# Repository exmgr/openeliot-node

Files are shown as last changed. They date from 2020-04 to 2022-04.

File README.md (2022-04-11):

## Εισαγωγή
Το OpenELIoT Νode αποτελεί τον κόμβο καταγραφής δεδομένων από περιβαλλοντικούς αισθητήρες και είναι μέρος του έργου [Open ELIoT](https://github.com/exmgr/OpenELIoT). Αποτελείται από την ίδια την ηλεκτρονική συσκευή καταγραφής και το υλισμικό της το οποίο βρίσκεται σε αυτό το αποθετήριο. 
Είναι ένα αυτόνομα σύστημα καταγραφής κατασκευασμένο να λειτουργεί για μεγάλα χρονικά διαστήματα σε απομακρυσμένες περιοχές αντλώντας ηλιακή ενέργεια για την φόρτιση των μπαταριών του και το περίβλημά του είναι ανθεκτικό στις καιρικές συνθήκες (ήλιος, βροχή, υγρασία).

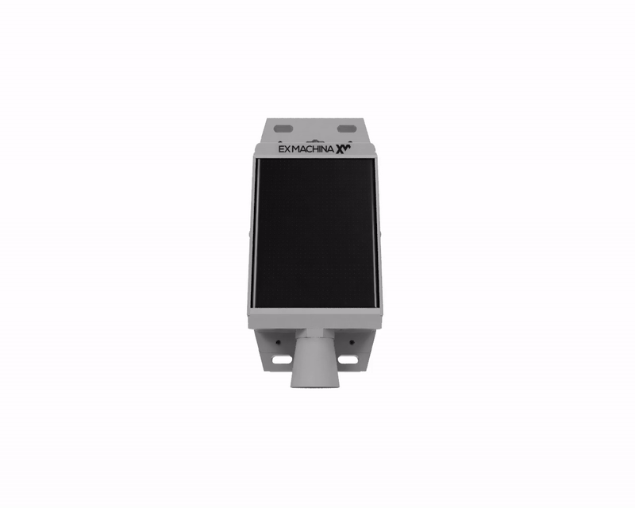
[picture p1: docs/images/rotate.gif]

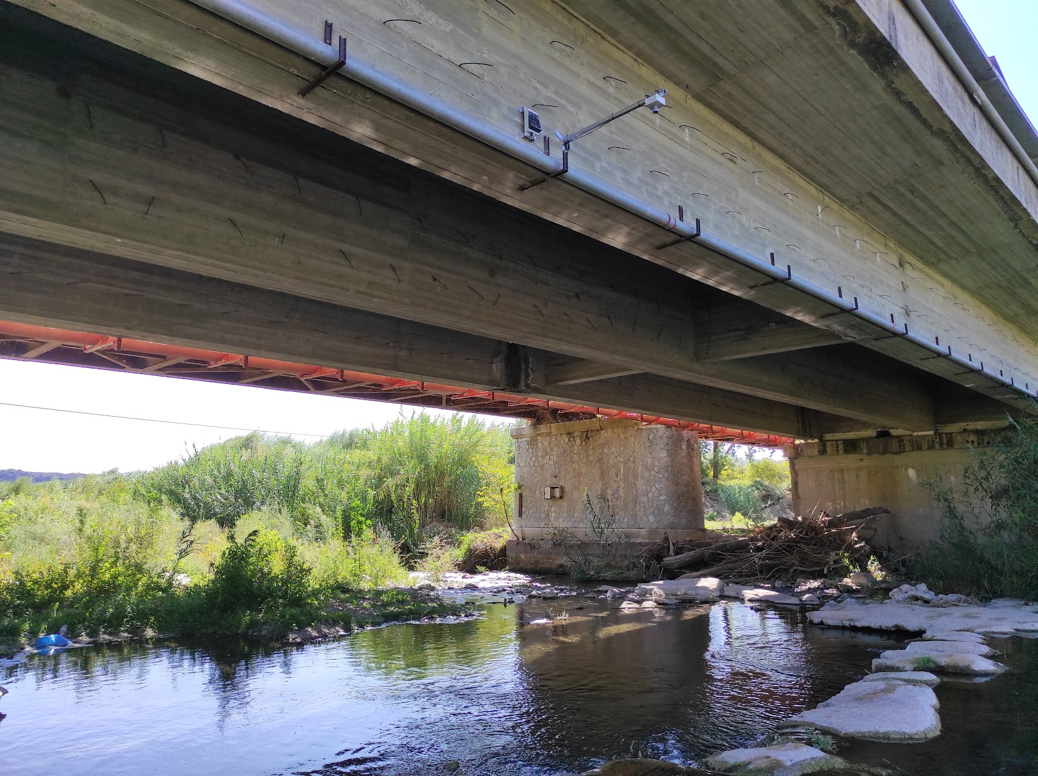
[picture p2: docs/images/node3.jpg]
OpenELIoT Node


## Αρχιτεκτονική Node

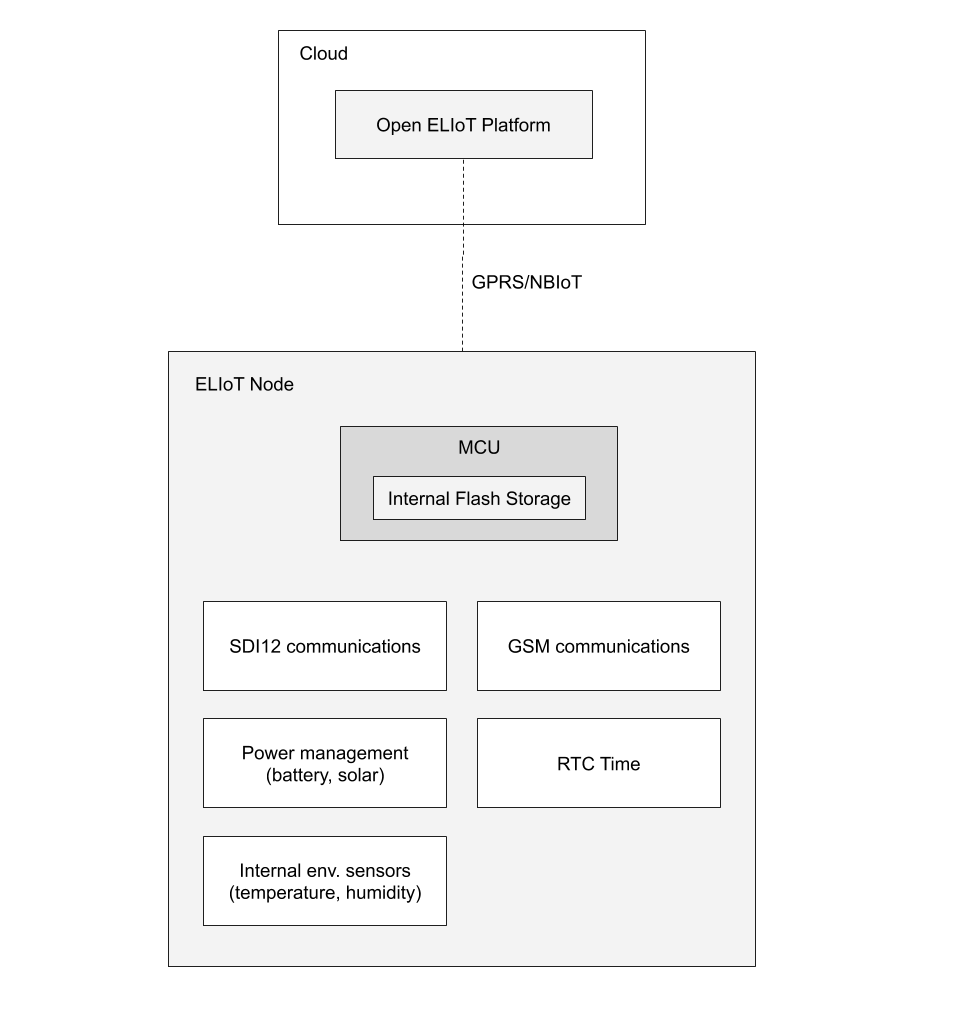
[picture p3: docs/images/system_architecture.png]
Αρχιτεκτονική συστήματος


Το ELIoT node αποτελεί κεντρικό δομικό στοιχείο του κάθε σταθμού καταγραφής OpenELIoT, στον οποίο συνδέονται όλοι οι αισθητήρες των οποίον τα δεδομένα καταγράφει, αποθηκεύει και αποστέλλει στην πλατφόρμα. Αποτελείται από κυκλώματα που του επιτρέπουν να επικοινωνεί μέσω ποικίλων πρωτοκόλλων με τους αισθητήρες, κυκλώματα διαχείρισης ενέργειας για αυτόνομη λειτουργία με φόρτιση των μπαταριών από τον ήλιο και υποστήριξη τεχνολογιών ασύρματης επικοινωνίας για αποστολή των δεδομένων.

## Τεχνικός οδηγός
Αναλυτική περιγραφή του συστήματος, οδηγίες για την κατασκευή, ρύθμιση και τον προγραμματισμού του υλισμικού ενός OpenELIoT Node βρίσκονται στον [τεχνικό οδηγό](docs/technical_guide.pdf)

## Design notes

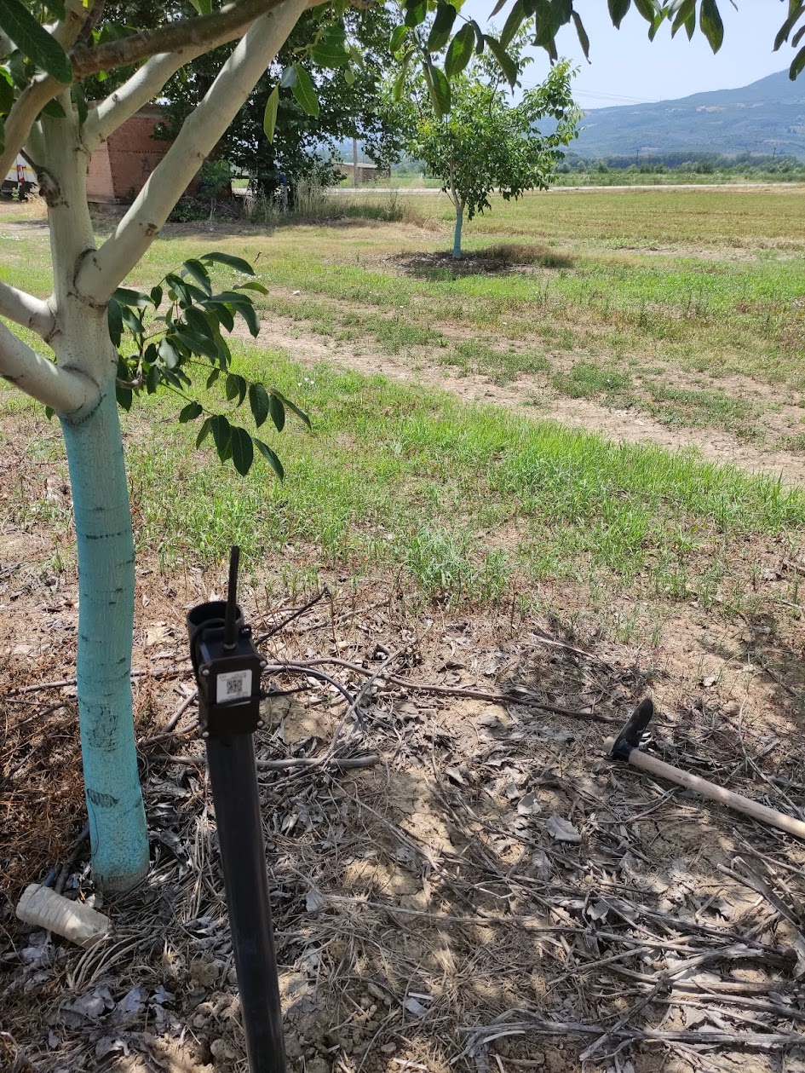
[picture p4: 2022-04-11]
docs/images/soil.jpg

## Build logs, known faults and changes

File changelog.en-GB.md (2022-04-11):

[1.64]
* Time source priority changed to HTTP first.

[1.63]
* CHanged battery sleep thersholds to 25/35%.

[1.61]
* Improved filtering of ADC battery measurement
* Light sensor tuning
* Detect system time drift using external RTC
* Check RTC drift on wakeup-self-test
* Added check to prevent significant time changes on RTC sync to prevent time errors

[1.58]
* Improved RTC auto sync
* Log RTC time source on sync for debugging

[1.56]
* Improved data acquisition from MaxBotix level sensor

[1.55]
* Decreased RTC auto sync interval to half a day

[1.54]
* Added UV index to weather telemetry

[1.53]
* Moved DFRobot water level sensor to another serial port due to stability issues 

[1.52]
* Light sensor stability bug fixes
* Log raw value of water presence sensor
* DFRobot ultrasonic serial port bug fix

[1.51]
* More flags submitted as attributes to aid with debugging

[1.50]
* Added IPFS support. Weather station measurements are submitted to IPFS during data submission.

[1.49]
* RTC auto-sync feature, where RTC is automatically synced on preset intervals.

[1.48]
* Added NTP sync support to TSIM7000.

[1.45]
* Lightning sensor tuned for improved precision. 

[1.44]
* Device can now keep working if external RTC fails by relying solely on the internal RTC.

[1.43]
* More robust handling on errors during data submission.
* Improved wind speed calculations for FineOffset weather stations.
* Added lightning sensor mode selection switch
* Added support for LTC2941 coulomb counter.
* Added INA218 current monitor support for monitoring solar power.

[1.42]
* Added Lightning sensor on/off flag.
* Added RTC sync remote control command.

[1.41]
* Added Aquatroll600 support.

[1.36]
* Added support for AS3936 lightning sensor.

[1.35]
* Added support DFRobot A02YYUW ultrasonic sensor. 

[1.33]
* FineOffset RF sniffing is automatically disabled to conserve energy after a number of unsuccessful attempts to receive a packet from a weather station.

[1.32]
* Added FineOffset sniffer auto-scan feature where the device listens for packets from a weather station and pairs itself to that specific weather station.
* Device now sleeps when waiting for the RF module to return a packet and is awaken on interrupt when a packet is received, to conserve energy.
* Submit more detailed configuration as device attributes.

[1.24]
* Improved ultrasonic sensor data filtering.

[1.23]
* Soil moisture measurement intervals can now be changed via remote control.

[1.19]
* Device can now be booted into "config mode" by holding user button for 3 seconds during boot. In config mode, device-specific configuration can be set via a serial console.

[1.18]
* Added support for RF sniffing telemetry data from FineOffset weather stations and logging them as telemetry.

[1.17]
* Implemented custom SDI12 driver.
* Added support for DFRobot throw-in liquid pressure sensor.
* Added support for Teros12 soil moisture sensor.
* Added support for DFRobot ultrasonic level sensor.
* Added support for serial channel on Maxbotix ultrasonic sensors.
* Added support for Aquatroll500 water quality sensor.

[1.16]
* Added TTGo TSIM support

[1.14]
* Adafruit FONA support discontinued
* SDI12 communications can be logged and submitted to TB for debugging.

[1.13]
* Added support for redirecting serial debug output via WiFi to timber.io for debugging.

[1.12]
* Added debug message level macros
* Added Thingsboard fallback device for when user config is corrupted.

[1.11]
* Sleep/sensor intervals are now measured as a reference of current time instead of the device boot time for more predictable operation.
* Added dew point to weather data

[1.8]
* Use external RTC to compensate drifting of external RTC for more precise wakeup intervals.

[1.7]
* Added support for Atmos41 weather station.
* SPIFFS file system can be formmated via remote-control.
* Added enable/disable flags for water level/quality sensors.
* Application-config flags are submitted as Thingsboard device attributes.

[1.3]
* Added support for PWM channel on MaxBotix ultrasonic sensors.
* Current device configuration is submitted as Thingsboard device attributes.

[1.2]
* Added low battery mode in which user-set sleep intervals are ignored and preset low-rate intervals are used instead to save battery.
* Added sleep-charge mode which puts the device in sleep when battery level is critically low and all functionality is disabled. Device functionality is restored only when battery is charged above a preset level.

[1.1]
* More detailed logging.
* Self-test after OTA. If fails, firmware is rolled back to previous version.

[1.0]
* Added support for OTA.
* GSM backend completely refactored to use TinyGSM.
* Added per-board config file.
* Added Support for WiPy.
* Added support for Adafruit Feather.

[0.3]
* Read battery voltage/pct from GSM module and add as diagnostics.
* Sync time from HTTP when everything else fails.
* Added BME280 for monitoring internal environment conditions.

[0.2]
* Send diagnostics as telemetry to Thingsboard.
* Added NBIoT support when using SIM7000.
* Added NodeMCU support.

[0.1]
* Added TTGO TFox compatibility.
* Added remote config.

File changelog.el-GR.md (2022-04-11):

[1.64]
* Time source priority changed to HTTP first.

[1.63]
* CHanged battery sleep thersholds to 25/35%.

[1.61]
* Βελτίωση φιλτραρίσματος της καταγραφής τάσης της μπαταρίας από ADC
* Συντονισμός του αισθητήρα κεραυνών
* Αναγνώριση και διόρθωση της απόκλισης της ώρας συστήματος χρησιμοποιώντας το εξωτερικό RTC
* ΈΛεγχος της απόκλισης της ώρας κατα το ξύπνημα στο self-test.
* Προστέθηκε έλεγχος που εμποδίζει τις μεγάλες μεταβολές ώρας κατα τον συγχρονισμό για αποφυγή μη έγκυρης ώρας

[1.58]
* Βελτίωση συγχρονσιμού ώρας
* Καταγραφή της πηγής της ώρας για αποσφαλμάτωση

[1.56]
* Βελτίωση ανάγνωσης δεδομένων από τον αισθητήρα στάθμης MaxBotix

[1.55]
* Μείωση του χρόνου αυτόματου συγχρονισμού ώρας σε μισή μέρα

[1.54]
* Προσθήκη δείκτη UV στην τηλεμετρία καιρού

[1.53]
* Μετακίνηση του αισθητήρα στάθμης DFRobot σε εναλλακτική σειριακή θύρα λόγω προβλημάτων σταθερότητας

[1.52]
* Βελτιστοποιημένη σταθερότητα αισθητήρα κεραυνών
* Διόρθωση σφάλματος στη σειριακή θύρα του ηχοβολιστικού DFRobot

[1.51]
* Εκτεταμένη αποστολή καταγραφής για διευκόλυνση της αποσφαλμάτωσης

[1.50]
* Προσθήκη υποστήριξης IPFS.
* Αποστολή δεδομένων μετεωρολογικού σταθμού στο IPFS

[1.49]
* Λειτουργία αυτόματου συγχρονισμού ρολογιού ανά τακτά χρονικά διαστήματα.

[1.48]
* Προσθήκη συγχρονισμού ώρας μέσω NTP στο TSIM7000.

[1.45]
* Βελτίωση των ρυθμίσεων του αισθητήρα κεραυνών για βελτιωμένη ακρίβεια.

[1.44]
* Η συσκευή μπορεί πλέον να λειτουργεί ακόμα και μετά από αποτυχία του εξωτερικού RTC, λειτουργόντας μόνο με τη χρήση του εσωτερικού RTC του ESP32.

[1.43]
* Ανθεκτικότερος χειρισμός σφαλμάτων κατά την αποστολή δεδομένων.
* Βελτίωση των υπολογισμών της ταχύτητας του ανέμου στους μετεωρολογικούς σταθμόυς FineOffset.
* Προστέθηκε διακόπτης επιλογής λειτουργίας του αισθητήρα κεραυνών.
* Προστέθηκε υποστήριξη του LTC2941 coulomb counter.
* Προστέθηκε υποστήριξη ΙΝΑ218 current monitor για παρακολούθηση ενέργειας του ηλιακού πάνελ.

[1.42]
* Προσθήκη διακόπτη ενεργ./απενεργ. για τον αισθτήρα κεραυνών.
* Προστέθηκε εντολή απομακρυσμένου ελέγχου για συγχρονισμό του RTC.

[1.41]
* Προσθήκη υποστήριξης του αισθητήρα ποιότητας νερού Aquatroll600.

[1.36]
* Προσθήκη υποστήριξης του αισθητήρα κεραυνών AS3936.

[1.35]
* Προσθήκη υποστήριξης για τον αισθητήρα στάθμης υπερήχων DFRobot A02YYUW.

[1.33]
* To RF sniffing απενεργοποιείται αυτόματα μετά απο αριθμό διαδοχικών αποτυχιών λήψης πακέτου από μετεωρολογικό σταθμό, για εξοικονόμηση ενέργειας.

[1.32]
* Προστέθηκε λειτουργία αυτόματης αναζήτησης στον FineOffset sniffer, κατα την οποία η συσκευή "ακούει" για πακέτα δεδομένων από μετεωρολογικούς σταθμους FineOffset και έπειτα δημιουργεί σύζευξη με τον συγκεκριμένο σταθμό.
* Η συσκευή βρίσκεται σε λειτουργία ύπνου όσο αναμένει πακέτα από το RF module, και ξυπνάει μόνο όταν ληφθεί το πακέτο γι εξοικονόμηση ενέργειας.
* Αποστολή περισσότερων ρυθμίσεων ως Thingsboard device attributes.

[1.24]
* Βελτίωση φιλτραρίσματος αναγνωσμένων δεδομένων των αισθητήρων υπερήχων.

[1.23]
* Ο χρόνος δειγματοληψίας του αισθητήρα υγρασίας εδάφους μπορεί να ρυθμιστεί απομακρυσμένα.

[1.19]
* Προσθήκη υποστήριξης λειτουργίας εύκολης ρύθμισης "config mode". Η συσκευή μπορεί να ξεκινήσει σε αυτη τη λειτουργία πατώντας το κουμπί χρήστη για 3 δευτ. κατά την εκκίνηση. Έπειτα με τη βοήθεια μιας σειριακής κονσόλας η συσκευή μπορεί να ρυθμιστεί με απλές εντολές.

[1.18]
* Προσθήκη υποστήριξης RF sniffing των μετεωρολογικών σταθμών της FineOffset και καταγραφή των δεδομένων τηλεμετρίας.

[1.17]
* Υλοποιήθηκε custom SDI12 driver.
* Προσθήκη υποστήριξης για τον αισθητήρα DFRobot throw-in liquid pressure sensor.
* Προσθήκη υποστήριξης για τον αισθητήρα υγρασίας εδάφους Teros12.
* Προσθήκη υποστήριξης για τον ultrasonic αισθητήρα στάθμης της DFRobot.
* Προσθήκη υποστήριξης σειριακού καναλιού για τον αισθητήρα στάθμης υπερήχων Maxbotix. 
* Προσθήκη υποστήριξης για τον αισθητήρα ποιότητας νερού Aquatroll500.

[1.16]
* Προσθήκη υποστήριξης για την πλακέτα TTGo TSIM.

[1.14]
* Αφαιρέθηκε η βιβλιοθήκη Adafruit FONA.
* Οι επικοινωνίες μεταξύ των συσκευών SDI12 μπορούν πλέον να καταγραφούν και να αποσταλούν ως τηλεμετρία στο Thingsboard για αποσφαλμάτωση.

[1.13]
* Η έξοδος της κονσόλας αποσφαλμάτωσης μπορεί να ανακατευθυνθεί μέσω WiFi στην υπηρεσία Timber.io, για διευκόλυνση της αποσφαλμάτωσης.

[1.12]
* Προστέθηκαν επίπεδα στα μηνύματα αποσφαλμάτωσης της κονσόλας (debug level macros)
* Προστέθηκε fallback συσκευή Thingsbaord, για την περίπτωση που καταστραφούν οι ρυθμίσεις του χρήστη στην εσωτερική μνήμη.

[1.11]
* Οι χρόνοι δειγματοληψίας πλέον υπολογίζονται με σημείο αναφοράς την τρέχουσα ώρα αντί για τον χρόνο τον οποίο μπήκε σε λειτουργία η συσκευή, ώστε η ώρα δειγματοληψίας να είναι προβλέψιμη.
* Προστέθηκε η παράμετρος "σημείο δρόσου" στις παραμέτρους του μετεωρολογικού σταθμου.
[1.8]
* Χρήση του εξωτερικού RTC για διόρθωση του drift του εσωτερικού RTC, για μεγαλύτερη ακρίβεια στους χρόνους δειγματοληψίας.

[1.7]
* Προσθήκη υποστήριξης του μετεωρολογικού σταθμου Atmos41.
* Το σύστημα αρχείων SPIFFS μπορεί να διαμορφωθεί μέσω απομακρυσμένου ελέγχου.
* Προστέθηκε διακόπτης ενεργ./απενεργοποίησης των αισθητήρων στάθμης/ποιότητας νερού.
* Οι ρυθμίσεις του app_config αποστέλλονται ως Thingsboard device attributes κατά την αποστολή δεδομένων για διευκόλυνση της αποσφαλμάτωσης.

[1.3]
* Προσθήκη υποστήριξης του PWM καναλιού στους MaxBotix ultrasonic αισθητήρες.
* Οι τρέχουσες ρυθμίσεις της συσκευής αποστέλλονται ως Thingsboard device attributes.

[1.2]
* Προστέθηκε λειτουργία χαμηλής μπαταρίας κατά την οποία η ρυθμίσεις χρόνων δειγματοληψίας του χρήστη αγνοούνται και η συσκευή μπαίνει σε λειτουργία αργής δειγματοληψίας για εξοικονόμηση ενέργειας.
* Προστέθηκε λειτουργία sleep-charge κατά την οποία η συσκευή μπαίνει σε λειτουργία ύπνου για εξοικονόμηση ενέργειας όταν η μπαταρία βρίσκεται σε κρίσιμα χαμηλά επίπεδα. Η πλήρης λειτουργικότητα της συσκευής επανέρχεται μόνο όταν το επίπεδο φόρτισης της μπαταρίας ανέβει πάνω από ένα προκαθορισμένο όριο.

[1.1]
* Αναλυτικότερη καταγραφή συμβάντων και σφαλμάτων.
* Αυτοέλεγχος της συσκευής μετά το ΟΤΑ. Σε περίπτωση αποτυχίας, το υλισμικό επανέρχεται στην προηγούμενη έκδοση.

[1.0]
* Προσθήκη ΟΤΑ (αποστολή απομακρυσμένων αναβαθμίσεων υλισμικού).
* Λειτουργικότητα GSM γράφτηκε από την αρχή για χρήση της βιβλιοθήκης TinyGSM.
* Προσθήκη αρχείου ρυθμίσεων ανα πλακέτα ανάπτυξης,
* Προσθήκη υποστήριξης πλακέτας WiPy.
* Προσθήκη υποστήριξης πλακέτας Adafruit Feather

[0.3]
* Ανάγνωση τάσης/κατάστασης φόρτισης μπαταρίας από το GSM module και αποθήκευση στα διαγνωστικά.
* Συγχρονισμός ώρας μέσω ΗΤΤP όταν οι υπόλοιπο μέθοδοι συγχρονισμού αποτύχουν.
* Προσθήκη του αισθητήρα ΒΜΕ280 για παρακολούθηση των εσωτερικών συνθηκών της συσκευής.

[0.2]
* Αποστολή διαγνωστικών ως τηλεμετρία στο Thingsboard.
* Προσθτέθηκε υποστήριξη NBIoT όταν υπάρχει διαθέσιμο το SIM7000.
* Προσθήκη υποστήριξης της πλακέτας NodeMCU.

[0.1]
* Προστέθηκε υποστήριξη της πλακέτας TTGO TFox.
* Προσθήκη δυνατότητας απομακρυσμένου ελέγχου.

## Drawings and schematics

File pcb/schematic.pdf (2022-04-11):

### BME280 Module (i2c mode)

### Generic AHT10 module

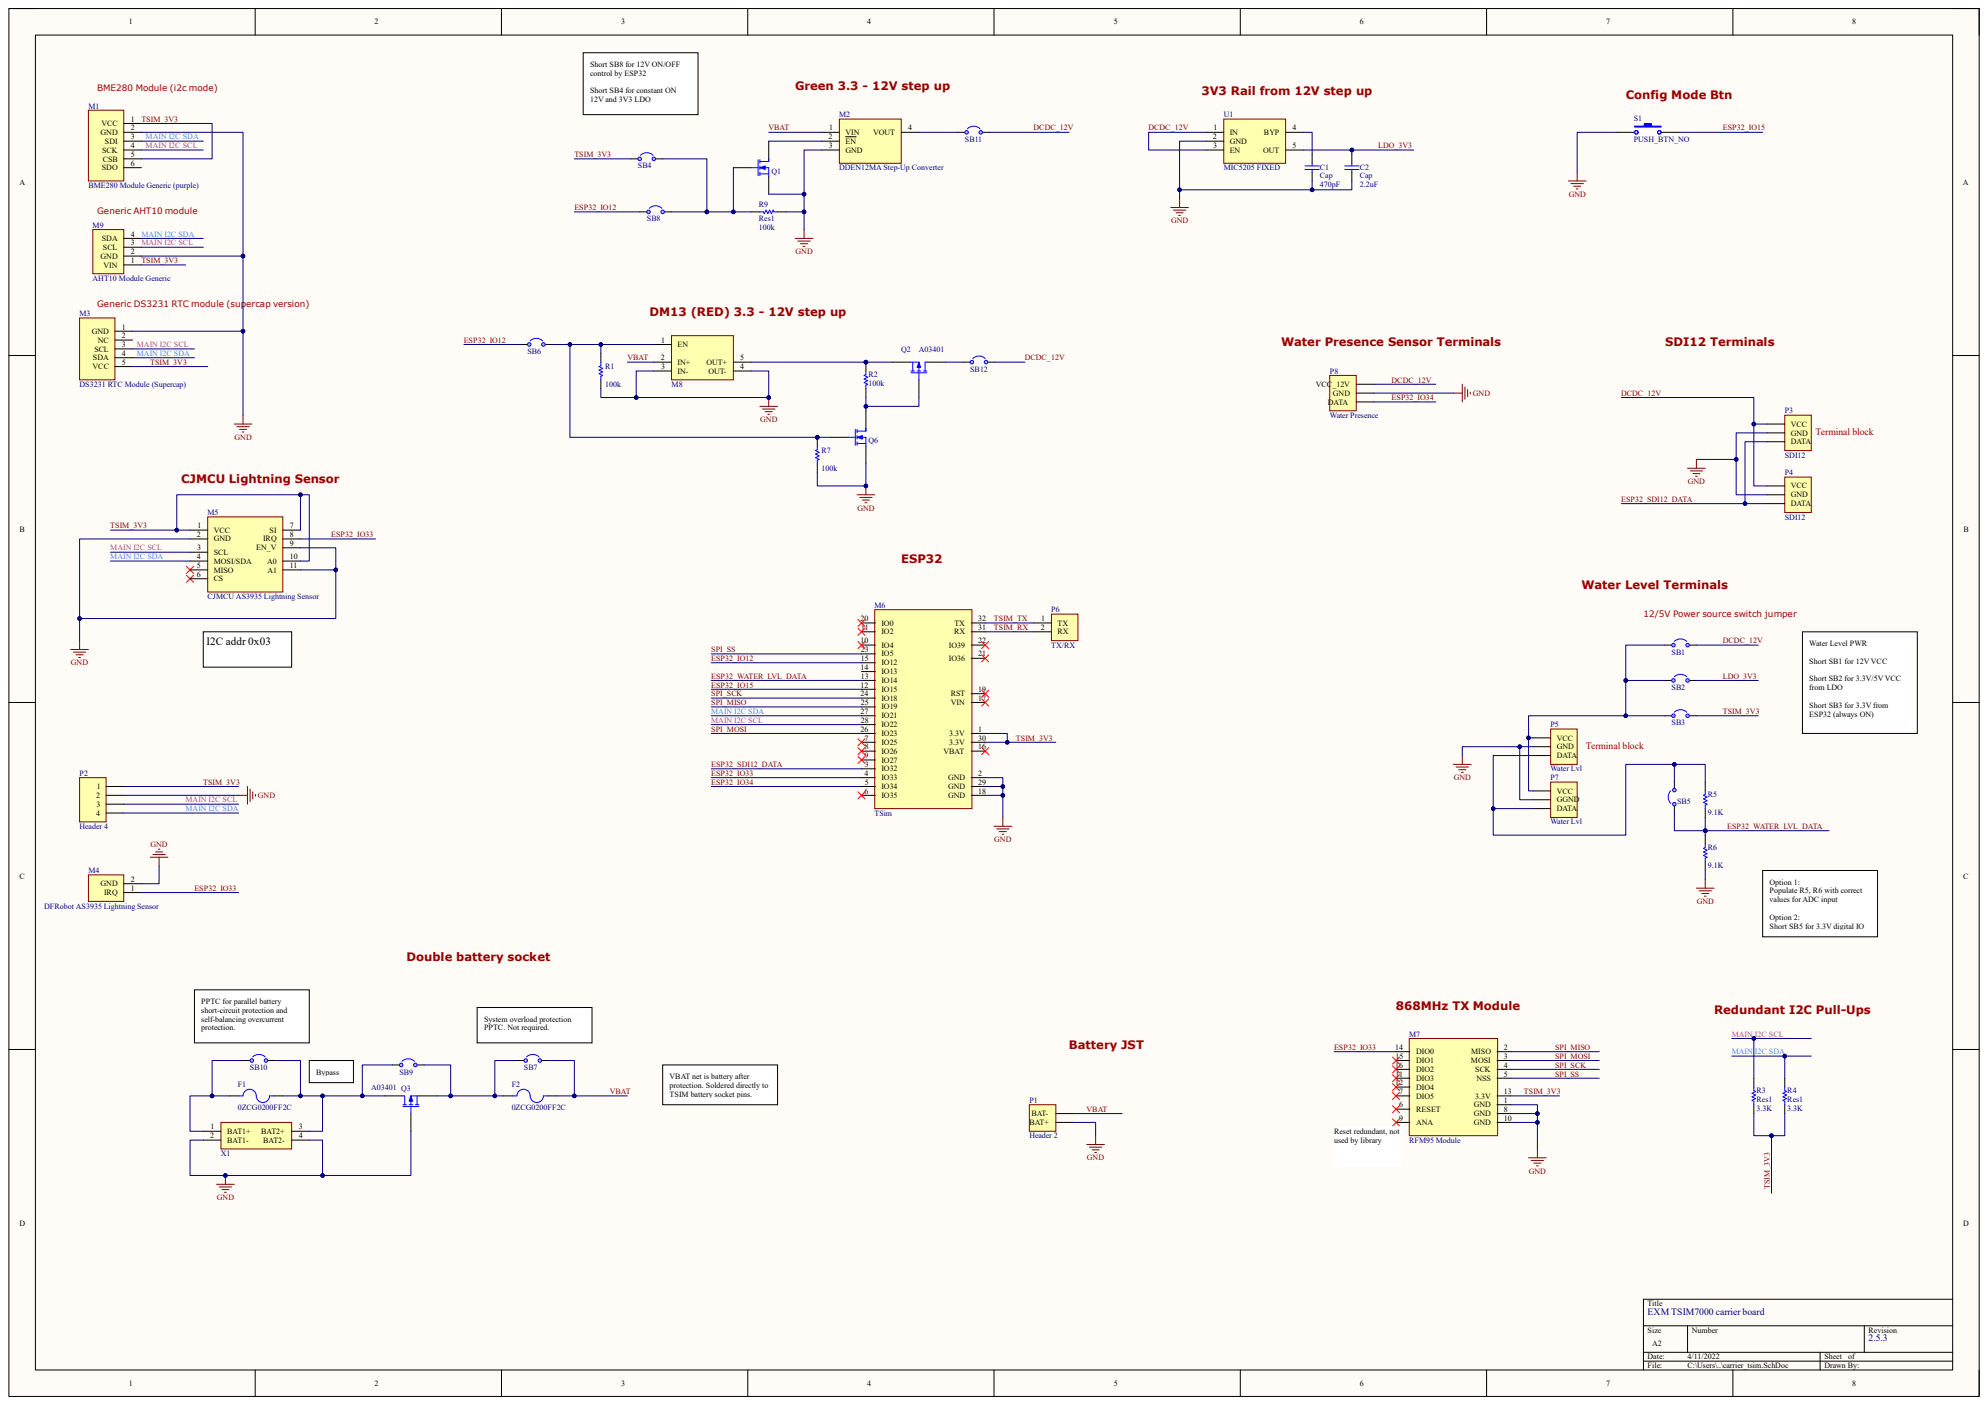
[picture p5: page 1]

Short SB8 for 12V ON/OFF
control by ESP32

Short SB4 for constant ON
12V and 3V3 LDO

3V3 Rail from 12V step up

Generic DS3231 RTC module (supercap version)

Water Presence Sensor Terminals

12/5V Power source switch jumper

Option 1:
Populate R5, R6 with correct
values for ADC input

Option 2:
Short SB5 for 3.3V digital IO

PPTC for parallel battery
short-circuit protection and
self-balancing overcurrent
protection.

Redundant I2C Pull-Ups 868MHz TX Module

protection. Soldered directly to
TSIM battery socket pins.

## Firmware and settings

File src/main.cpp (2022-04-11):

#include <Arduino.h>
#include <stdlib.h>
#include <ctime>
#include <sys/time.h>
#include "common.h"
#include "call_home.h"
#include "const.h"
#include "flash.h"
#include "globals.h"
#include "water_sensor_data.h"
#include "utils.h"
#include "gsm.h"
#include "rtc.h"
#include "log.h"
#include "tests.h"
#include "test_utils.h"
#include "sleep_scheduler.h"
#include "water_sensors.h"
#include <Wire.h>
#include <RtcDS3231.h>
#include "device_config.h"
#include "battery.h"
#include "int_env_sensor.h"
#include <SPIFFS.h>
#include "ota.h"
#include "atmos41.h"
#include "rom/rtc.h"
#include "fo_sniffer.h"
#include "fo_uart.h"
#include "fo_data.h"
#include "config_mode.h"
#include "driver/rtc_io.h"
#include "esp_sleep.h"
#include "lightning.h"
#include "battery_gauge.h"
#include "solar_monitor.h"
#include "ipfs_client.h"

// For testing
#include "http_request.h"
#include "sleep_scheduler.h"
#include "data_store_reader.h"
#include "sdi12_log.h"
#include "tb_sdi12_log_json_builder.h"
#include "wifi_modem.h"
#include "sdi12.h"
#include "sdi12_sensor.h"
#include "dfrobot_liquid.h"
#include "teros12.h"
#include "soil_moisture_data.h"
#include "water_level.h"
#include "water_presence.h"
#include "aquatroll.h"

/******************************************************************************
 * Setup
 *****************************************************************************/
void setup() 
{
	Serial.begin(115200);
		
	Utils::serial_style(STYLE_BLUE);
	Utils::print_separator(F("BOOTING"));
	Utils::serial_style(STYLE_RESET);
	debug_print(F("\n\n"));

	//
	// Print on-boot info
	// 
	DeviceConfig::init();

	Utils::serial_style(STYLE_GREEN);
	debug_print(F("Reset reason: "));
	Utils::print_reset_reason();
	debug_println();
	Utils::serial_style(STYLE_RESET);


	#if DEBUG
		Utils::serial_style(STYLE_RED);
		Utils::print_block(F("Debug build"));
		Utils::serial_style(STYLE_RESET);
		debug_println();
	#else
		Utils::serial_style(STYLE_BLUE);	
		Utils::print_block(F("Release build"));
		Utils::serial_style(STYLE_RESET);
		debug_println();
	#endif

	Utils::print_flags();
	debug_println();

	// Device info
	Utils::print_separator(F("DEVICE INFO"));

	// Board name
	debug_print(F("Board: "));
	debug_println(BOARD_NAME);

	debug_print(F("Version: "));
	debug_println(FW_VERSION, DEC);

	char mac[20] = "";
	Utils::get_mac(mac, sizeof(mac));
	debug_print(F("MAC: "));
	debug_println(mac);
	debug_print(F("APN: "));
	debug_println(DeviceConfig::get_cellular_apn());
	Serial.print(F("TB Server: "));
	Serial.println(TB_SERVER);
	debug_print(F("TB Access Token: "));
	debug_println(DeviceConfig::get_tb_device_token());

	if(FLAGS.WATER_QUALITY_SENSOR_ENABLED)
	{
		debug_print(F("AquaTROLL Model: "));

		if(AQUATROLL_MODEL == AQUATROLL_MODEL_400)
		{
			debug_println(F("400"));
		}
		else if(AQUATROLL_MODEL == AQUATROLL_MODEL_500)
		{
			debug_println(F("500"));
		}
		else if(AQUATROLL_MODEL == AQUATROLL_MODEL_600)
		{
			debug_println(F("600"));
		}
		else
		{
			debug_println_e(F("Invalid AquaTROLL model selected"));
		}
	}

	debug_println();

	// Print program info
	debug_print(F("Program size: "));
	debug_print(ESP.getSketchSize() / 1024, DEC);

	debug_println(F("KB"));
	debug_print(F("Free program space: "));
	debug_print(ESP.getFreeSketchSpace() / 1024, DEC);
	debug_println(F("KB"));

	debug_print(F("Free heap: "));
	debug_print(ESP.getFreeSketchSpace(), DEC);
	debug_println(F("B"));

	debug_print(F("CPU freq: "));
	debug_print(ESP.getCpuFreqMHz());
	debug_println("MHz");

	Utils::print_separator(NULL);
	debug_println();

	// Check if credentials are configured and if not use fallback
	Utils::check_credentials();

	// Turn lightning sensor off before config mode.
	// If IRQ was not cleared before device restart
	// Lightning::off();

	// Handle config mode if needed
	ConfigMode::handle();

	//
	// Init 
	// Order important

	// Init main I2C1 bus
	Wire.begin(PIN_I2C1_SDA, PIN_I2C1_SCL, 100000);

	// Init ext RTC first and sync system time
	RTC::init();
	RTC::enable_timechange_safety(false);
	RTC::sync_time_from_ext_rtc();
	RTC::enable_timechange_safety(true);

	#ifdef TCALL_H
		// Turn IP5306 power boost OFF to reduce idle current
		Utils::ip5306_set_power_boost_state(false);
	#endif

	delay(100);
	IntEnvSensor::init();
	Battery::init();
	BatteryGauge::init();
	SolarMonitor::init();
	delay(100);
	Flash::mount();
	Flash::ls();
	GSM::init();
	WaterSensors::init();
	WaterLevel::init();
	WaterPresence::init();
	Atmos41::init();

	if(FO_SOURCE == FO_SOURCE_SNIFFER)
	{
		Serial.println(F("FO source sniffer"));
		FoSniffer::init();

		// If no FO node id is set, scan
		if(DeviceConfig::get_fo_sniffer_id() == 0 && DeviceConfig::get_fo_enabled())
		{
			debug_println_e(F("No FO weather station id is set, scanning."));
			FoSniffer::scan_fo_id(true);
		}
	}
	else if(FO_SOURCE == FO_SOURCE_UART)
	{
		Serial.println(F("FO source UART"));
		FoUart::init();
	}
	
	// Log boot now that memory has been inited
	Log::log(Log::Code::BOOT, FW_VERSION, (int)rtc_get_reset_reason(0));

	// Log mac address
	Utils::log_mac();

	// Log and print battery
	Battery::log_adc();
	Battery::log_solar_adc();
	IntEnvSensor::log();

	// Log and print Battery gauge
	BatteryGauge::print();
	BatteryGauge::log();

	// Log and print Solar Monitor
	SolarMonitor::print();
	SolarMonitor::log();

	// Device info
	DeviceConfig::print_current();

	//
	// Boot tests
	//
	Utils::boot_self_test();

	// Check if boot is after OTA
	if(DeviceConfig::get_ota_flashed())
	{
		OTA::handle_first_boot();
	}

	//
	// Check if device needs to be in sleep mode in case this is after a brown out
	//
	Serial.println(F("Checking sleep charge"));
	Battery::sleep_charge();

	if(FLAGS.LIGHTNING_SENSOR_ENABLED)
	{
		if(Lightning::on() != RET_OK)
		{
			Log::log(Log::LIGHTNING_FAILED_TO_START, LIGHTNING_SENSOR_MODULE, LIGHTNING_I2C_ADDR);
		}
	}

	//
	// Check if reboot clean
	// Reboot is considered clean when the clean_boot flag is set
	// Otherwise the device was hard-reset or reboot was unexpected (exception)
	//
	if(DeviceConfig::get_clean_reboot())
	{
		Utils::serial_style(STYLE_GREEN);
		debug_println(F("Clean boot"));
		Utils::serial_style(STYLE_RESET);

		// Reset flag
		DeviceConfig::set_clean_reboot(false);
		DeviceConfig::commit();
	}
	else
	{
		Utils::serial_style(STYLE_RED);
		debug_println(F("Boot is not clean (not intentional)"));
		Utils::serial_style(STYLE_RESET);
	}

	//
	// Turn on GSM to check if SIM card present and sync time
	// In debug mode sync time from external RTC
	if(FLAGS.DEBUG_MODE && RTC::tstamp_valid(RTC::get_timestamp()))
	{
		debug_println(F("Debug mode, using ext RTC time."));
		RTC::sync_time_from_ext_rtc();
	}
	else
	{
		if(GSM::on() != RET_ERROR)
		{ 
			// 
				// Get SIM CCID to check for its presence
			// 
			if(!GSM::is_sim_card_present())
			{
				Utils::serial_style(STYLE_RED);
				debug_println(F("No SIM card detected!"));
				Utils::serial_style(STYLE_RESET);

				Log::log(Log::GSM_NO_SIM_CARD);
			}

			//
			// Sync RTC
			// On boot sync, disable timechange safety
			if(RTC::sync(false) != RET_OK) // RTC turns GSM ON
			{
				Utils::serial_style(STYLE_RED);
				debug_println(F("Failed to sync time, system has no source of time."));
				Utils::serial_style(STYLE_RESET);
			}
			else
			{
				debug_println(F("Time sync successful."));
				RTC::print_time();
			}
		}
	}

	//////////////////////////////////////////////////////////////////////////////////////////

	// TODO: Make all tasks run on boot and remove this
	if(FLAGS.WATER_QUALITY_SENSOR_ENABLED || FLAGS.WATER_LEVEL_SENSOR_ENABLED)
	{
		Utils::serial_style(STYLE_MAGENTA);
		debug_println(F("Reading: Read water sensors"));
		Utils::serial_style(STYLE_RESET);
		WaterSensors::log();
	}
	if(FLAGS.ATMOS41_ENABLED)
	{
		Utils::serial_style(STYLE_CYAN);
		debug_println(F("Reading: Read weather station"));
		Utils::serial_style(STYLE_RESET);
		Atmos41::measure_log();
	}
	if(FLAGS.SOIL_MOISTURE_SENSOR_ENABLED)
	{
		Utils::serial_style(STYLE_CYAN);
		debug_println(F("Reading: Read soil moisture sensor"));
		Utils::serial_style(STYLE_RESET);
		Teros12::log();
	}

	Utils::serial_style(STYLE_BLUE);
	debug_println(F("Reason: Call home"));
	Utils::serial_style(STYLE_RESET);
	CallHome::start();

	Utils::print_separator(F("SETUP COMPLETE"));
}

/******************************************************************************
 * Wake up self test
 * On each wake up, a self test checks if main parameters to see if it is OK
 * to proceed with normal operation (measure, send data etc.)
 * If not, regular wake up is not executed and the device goes back to sleep
 * until next wake up event.
 *****************************************************************************/
RetResult wakeup_self_test()
{
	RetResult ret = RET_OK;

	// Check if RTC returns invalid value
	int drift = RTC::detect_drift();
	if(!RTC::tstamp_valid(RTC::get_timestamp()) || drift > 0)
	{
		if(GSM::on() != RET_OK)
		{
			debug_println(F("Could not turn on GSM"));
			ret = RET_ERROR;
		}

		if(drift > 0)
		{
			debug_print(F("RTC drift detected: "));
			debug_println(drift, DEC);
			Log::log(Log::RTC_DRIFT_DETECTED, drift, RTC::get_external_rtc_timestamp());
		}
		else
		{
			debug_println_e(F("RTC returns invalid timestamp, syncing..."));
		}

		//
		// Sync RTC
		//	
		if(RTC::sync() != RET_OK)
		{
			debug_println(F("Failed to sync time."));
			ret = RET_ERROR;
		}
		else
		{
			debug_println(F("Time sync successful."));
			RTC::print_time();
		}
	}

	if(ret != RET_OK)
	{
		Log::log(Log::WAKEUP_SELF_TEST_FAILED);
	}

	return ret;
}

/******************************************************************************
* Main loop
******************************************************************************/
void loop()
{
	// Handle battery sleep charge if needed
	if(Battery::get_current_mode() == BATTERY_MODE::BATTERY_MODE_SLEEP_CHARGE)
	{
		Battery::sleep_charge();
	}

	//
	// Go to sleep
	//
	SleepScheduler::sleep_to_next();

	//
	// Wake up
	//

	// Woke up on IRQ from lightning sensor?
	// Handle otherwise go back to sleep
	if(FLAGS.LIGHTNING_SENSOR_ENABLED && esp_sleep_get_wakeup_cause() == ESP_SLEEP_WAKEUP_EXT0)
	{
		Lightning::handle_irq();
		return;
	}

	// Do not log when waking up for FO Sniff
	if(!SleepScheduler::wakeup_reason_is(SleepScheduler::REASON_FO))
	{
		IntEnvSensor::log();
	}

	// Do wake up self test
	if(wakeup_self_test() != RET_OK)
	{
		debug_println_e(F("Wake up self test failed, going back to sleep."));
	}
	else
	{
		//
		// Tasks executed only when wakeup self test passed
		//

		//
		// Sniff FO weather station
		//
		if(SleepScheduler::wakeup_reason_is(SleepScheduler::REASON_FO))
		{
			debug_println_i(F("Reason: Sniff FO weather station."));
			
			if(!DeviceConfig::get_fo_enabled())
			{
				debug_println_e(F("FO sniffer disabled, sniffing aborted."));
			}
			else
			{
				if(FO_SOURCE == FO_SOURCE_SNIFFER)
					FoSniffer::handle_sniff_event();
				else if(FO_SOURCE == FO_SOURCE_UART)
					FoUart::handle_scheduled_event();
			}
		}

		//
		// Measure water quality
		//
		if(SleepScheduler::wakeup_reason_is(SleepScheduler::REASON_READ_WATER_SENSORS))
		{
			debug_println_i(F("Reason: Read water sensors"));

			if(!FLAGS.WATER_QUALITY_SENSOR_ENABLED &&  !FLAGS.WATER_LEVEL_SENSOR_ENABLED)
			{
				debug_println_e(F("Water sensors disabled, measurement aborted."));
			}
			else
			{
				WaterSensors::log();
			}
		}

		//
		// Measure soil moisture
		//
		if(SleepScheduler::wakeup_reason_is(SleepScheduler::REASON_READ_SOIL_MOISTURE_SENSOR))
		{
			debug_println_i(F("Reason: Read soil moisture"));

			if(!FLAGS.SOIL_MOISTURE_SENSOR_ENABLED)
			{
				debug_println_e(F("Soil moisture sensor disabled, measurement aborted."));
			}
			else
			{
				Teros12::log();
			}
		}

		//
		// Measure weather data
		//
		if(SleepScheduler::wakeup_reason_is(SleepScheduler::REASON_READ_WEATHER_STATION))
		{
			debug_println_i(F("Reason: Read weather station"));

			if(!FLAGS.ATMOS41_ENABLED)
			{
				debug_println_e(F("Weather station disabled, measurement aborted."));
			}
			else
			{
				Atmos41::measure_log();
			}
		}
	}
	
	if(SleepScheduler::wakeup_reason_is(SleepScheduler::REASON_CALL_HOME))
	{
		debug_println_i(F("Reason: Call home"));
		CallHome::start();
	}

	debug_println(F("------------------------------------------------"));
}

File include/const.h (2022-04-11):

#ifndef CONST_H
#define CONST_H
#include <inttypes.h>
#include "sleep_scheduler.h"
#include "credentials.h"


/******************************************************************************
 * Misc
 *****************************************************************************/
/** Serial output baud */
const int SERIAL_MONITOR_BAUD = 115200;

/**
 * Seconds from unix epoch to 01/01/2000 00:00:00. Used to convert time from
 * RTC to UNIX timestamp used by ESP32s internal RTC
*/
const int SECONDS_IN_2000 = 946684800;

/** Buffer size for URLs */
const int URL_BUFFER_SIZE = 128;

/** Buffer size for URL's host part (used when exploding URLs) */
const int URL_HOST_BUFFER_SIZE = 60;

/** Larger buffer size for storing larger URL with many params (eg. thingsboard shared attrs) */
const int URL_BUFFER_SIZE_LARGE = 256;

/** Max sleep time for any event (main sleep). Used as a fail safe in case of wrong calculations */
const int MAX_SLEEP_TIME_SEC = 60 * 60 * 24; // One day

const int MAX_SLEEP_CORRECTION_SEC = 60 * 5; // 5 mins

/** Min/max allowed values for calling home interval (mins) */
const int CALL_HOME_INT_MINS_MIN = 1;           // 1 min
const int CALL_HOME_INT_MINS_MAX = 24 * 60 * 2; // 2 days

/** Min/max allowed values for water sensors measuring interval (mins) */
const int MEASURE_SENSORS_INT_MINS_MIN = 1;           		// 1 min
const int MEASURE_WATER_SENSORS_INT_MINS_MAX = 24 * 60 * 1; // 1 day

/** A timestamp must be in this range to be considered valid. y2k bug all over again.
 * Temp solution
 * value */
const unsigned long FAIL_CHECK_TIMESTAMP_START = 1567157191;
const unsigned long FAIL_CHECK_TIMESTAMP_END = 2072091600;

/** Samples configuration for analog */
const int ADC_CYCLES = 128;

/** Samples to average when reading battery voltage with internal ADC */
const int ADC_BATTERY_LEVEL_SAMPLES = 20;

/** Time user has to hold button to enter config mode */
const int CONFIG_MODE_BTN_HOLD_TIME_MS = 2000;

/******************************************************************************
* Debug
******************************************************************************/
const char DEBUG_LEVEL_ERROR_STYLE[] = "\033[31m"; // Red
const char DEBUG_LEVEL_WARNING_STYLE[] = "\033[33m"; // Yellow
const char DEBUG_LEVEL_INFO_STYLE[] = "\033[34m"; // Blue

const char TIMBER_API_URL[] = "https://logs.timber.io/sources/" TIMBER_SOURCE_ID "/frames";
const char TIMBER_AUTH_HEADER[] = "Bearer " TIMBER_API_KEY;

/** Length of Wifi Serial buffer for storing messages temporarily */
const int WIFI_SERIAL_BUFFER_SIZE = 512;

/******************************************************************************
* WiFi
******************************************************************************/
/** Timeout when trying to connect to network */
const int WIFI_CONNECT_TIMEOUT_SEC = 10;

/******************************************************************************
 * Data stores
 *****************************************************************************/
/** Maximum length for file path buffers */
const int FILE_PATH_BUFFER_SIZE = 25;

/** Max tries when looking for an unused filename before failing */
const int FILENAME_POSTFIX_MAX = 100;

/** Max number of files to delete when cleaning up store. Store is full when max
 * num of files is reached. */
const int STORE_CLEANUP_FILE_COUNT = 500;

/** Max number of files allowed in a directory. When num is exceeded, cleanup
 * is triggered */
const int STORE_MAX_FILE_COUNT = 1000;

/******************************************************************************
 * Telemetry data
 *****************************************************************************/
const int TELEMETRY_DATA_JSON_OUTPUT_BUFF_SIZE = 2048;

/******************************************************************************
 * Water Sensor data
 *****************************************************************************/
/** Path in data store where sensor data is stored */
const char* const WATER_SENSOR_DATA_PATH = "/was";

/** Arduino JSON doc size */
const int WATER_SENSOR_DATA_JSON_DOC_SIZE = 1024;
/** Sensor data entries to group into a single json packet for submission */
const int WATER_SENSOR_DATA_ENTRIES_PER_SUBMIT_REQ = 8;

// Telemetry key names
const char WATER_SENSOR_DATA_KEY_TIMESTAMP[] = "ts";
const char WATER_SENSOR_DATA_KEY_DISSOLVED_OXYGEN[] = "s_do";
const char WATER_SENSOR_DATA_KEY_TEMPERATURE[] = "s_temp";
const char WATER_SENSOR_DATA_KEY_PH[] = "s_ph";
const char WATER_SENSOR_DATA_KEY_CONDUCTIVITY[] = "s_cond";
const char WATER_SENSOR_DATA_KEY_ORP[] = "s_orp";
const char WATER_SENSOR_DATA_KEY_PRESSURE[] = "s_press";
const char WATER_SENSOR_DATA_KEY_DEPTH_CM[] = "s_depth_cm";
const char WATER_SENSOR_DATA_KEY_DEPTH_FT[] = "s_depth_ft";
const char WATER_SENSOR_DATA_KEY_TSS[] = "s_tss";
const char WATER_SENSOR_DATA_KEY_WATER_LEVEL[] = "s_wl";
const char WATER_SENSOR_DATA_KEY_WATER_PRESENCE[] = "s_presence";
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

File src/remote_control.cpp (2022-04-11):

#include "remote_control.h"
#include "HardwareSerial.h"
#include "water_sensors.h"
#include "device_config.h"
#include "gsm.h"
#include "sleep_scheduler.h"
#include "http_request.h"
#include "globals.h"
#include <TinyGsmClient.h>
#include <Update.h>
#include "utils.h"
#include "ota.h"
#include "call_home.h"
#include "test_utils.h"
#include "fo_sniffer.h"
#include "rtc.h"
#include "common.h"

/******************************************************************************
 * Routines for controlling the device remotely through thingsboard.
 * Responsible for requesting remote control data from TB and then executing
 * the requested configs/actions.
 *****************************************************************************/
namespace RemoteControl
{
	//
	// Private funcs
	//
	RetResult json_to_data_struct(const JsonObject &json, RemoteControl::Data *data);

	RetResult handle_user_config(JsonObject json);
	RetResult handle_reboot(JsonObject json);
	RetResult handle_format_spiffs(JsonObject json);
	RetResult handle_rtc_sync(JsonObject json);
	void set_reboot_pending(bool val);

	void set_last_error(int error);

	/** 
	 * Set when reboot command is received in remote control data so that device can be 
	 * rebooted when calling home handling ends.
	 */
	bool _reboot_pending = false;

	/** Last error code */
	int _last_error = 0;

	/******************************************************************************
	 * Handle remote control
	 * First some of the current settings are published as client attributes to the
	 * device in TB.
	 * Then remote control data is requested (which are shared attributes) and applied
	 *****************************************************************************/
	RetResult start()
	{
		debug_println(F("Remote control handling."));

		set_last_error(ERROR_NONE);

		//
		// Send request
		//
		char url[URL_BUFFER_SIZE_LARGE] = "";

		Utils::tb_build_attributes_url_path(url, sizeof(url));

		HttpRequest http_req(GSM::get_modem(), TB_SERVER);
		http_req.set_port(TB_PORT);
				
		RetResult ret = RET_ERROR;

		debug_println(F("Getting TB shared attributes."));
		ret = http_req.get(url, g_resp_buffer, sizeof(g_resp_buffer));

		if(ret != RET_OK)
		{
			debug_println(F("Could not send request for remote control data."));
			
			Log::log(Log::RC_REQUEST_FAILED, http_req.get_response_code());

			set_last_error(ERROR_REQUEST_FAILED);

			return RET_ERROR;
		}

		debug_println(F("Remote control raw data:"));
		debug_println(F(g_resp_buffer));

		//
		// Deserialize received data
		//
		StaticJsonDocument<REMOTE_CONTROL_JSON_DOC_SIZE> json_remote;
		DeserializationError error = deserializeJson(json_remote, g_resp_buffer, strlen(g_resp_buffer));

		// Could not deserialize
		if(error)
		{
			Utils::serial_style(STYLE_RED);
			debug_println(F("Could not deserialize received JSON, aborting."));
			Utils::serial_style(STYLE_RESET);
			
			Log::log(Log::RC_PARSE_FAILED);

			return RET_ERROR;
		}

		debug_println(F("Remote control JSON: "));
		serializeJsonPretty(json_remote, Serial);
		debug_println();

		// Get shared attributes key
		if(!json_remote.containsKey("shared"))
		{
			debug_println(F("Returned JSON has no remote attributes."));
			Log::log(Log::RC_INVALID_FORMAT);
			
			return RET_ERROR;
		}
		JsonObject json_shared = json_remote["shared"];

		// At least id key must be present
		if(!json_shared.containsKey(RC_TB_KEY_REMOTE_CONTROL_DATA_ID))
		{
			debug_println(F("Returned JSON has no data id."));
			Log::log(Log::RC_INVALID_FORMAT);

			return RET_ERROR;
		}

		//
		// Check if ID is new
		// If remote control ID is old, remote control data is ignored
		// ID is new when it is different than the one stored from the previous remote control
		long long new_data_id = (int)json_shared[RC_TB_KEY_REMOTE_CONTROL_DATA_ID];

		debug_print(F("Remote control data id: Current "));
		debug_print(DeviceConfig::get_last_rc_data_id());
		debug_print(F(" - Received "));
		debug_println((int)new_data_id);

		// Is it new?
		if(new_data_id == DeviceConfig::get_last_rc_data_id())
		{
			Utils::serial_style(STYLE_RED);
			debug_println(F("Received remote control data is old, ignoring."));
			Utils::serial_style(STYLE_RESET);	
			return RET_OK;
		}
		else
		{
			Log::log(Log::RC_APPLYING_NEW_DATA, new_data_id, DeviceConfig::get_last_rc_data_id());

			// Data id is new, update in config to avoid rc data from being applied every time
			DeviceConfig::set_last_rc_data_id(new_data_id);
			DeviceConfig::commit();
		}

		Utils::serial_style(STYLE_BLUE);
		debug_println(F("Received new remote control data. Applying..."));
		Utils::serial_style(STYLE_RESET);

		//
		// Handle/apply
		//

		// Handle user config
		RemoteControl::handle_user_config(json_shared);

		// Handle SPIFFS format
		RemoteControl::handle_format_spiffs(json_shared);

		// Handle RTC sync
		RemoteControl::handle_rtc_sync(json_shared);

		// Handle OTA if OTA requested
		if(json_shared.containsKey(RC_TB_KEY_DO_OTA) && ((bool)json_shared[RC_TB_KEY_DO_OTA]) == true)
		{
			OTA::handle_rc_data(json_shared);

			TestUtils::print_stack_size();
			
			// Send logs to report OTA events
			CallHome::handle_logs();
		}

		// Handle reboot
		RemoteControl::handle_reboot(json_shared);

		return RET_OK;
	}

	/******************************************************************************
	 * User config
	 *****************************************************************************/
	RetResult handle_user_config(JsonObject json)
	{
		debug_println(F("Applying new user config."));

		//
		// Water sensors measure interval
		//
		if(json.containsKey(RC_TB_KEY_MEASURE_WATER_SENSORS_INT))
		{
			int was_int = (int)json[RC_TB_KEY_MEASURE_WATER_SENSORS_INT];

			debug_print(F("Water sensors read interval: "));
			debug_print(F("Current "));
			debug_print(DeviceConfig::get_wakeup_schedule_reason_int(SleepScheduler::WakeupReason::REASON_READ_WATER_SENSORS));
			debug_print(F(" - New "));
			debug_print(was_int);
			debug_println(F(". "));

			// Check if value valid. 
			if(Utils::in_array(was_int, WAKEUP_SCHEDULE_VALID_VALUES, sizeof(WAKEUP_SCHEDULE_VALID_VALUES)) == -1)
			{
				debug_println(F("Invalid value, ignoring."));
				Log::log(Log::RC_WATER_SENSORS_READ_INT_SET_FAILED, was_int);
			}
			else
			{
				DeviceConfig::set_wakeup_schedule_reason_int(SleepScheduler::WakeupReason::REASON_READ_WATER_SENSORS, was_int);
				debug_println(F("Applied."));

				Log::log(Log::RC_WATER_SENSORS_READ_INT_SET_SUCCESS, was_int);
			}			
		}

		//
		// Weather station measure interval
		//
		if(json.containsKey(RC_TB_KEY_MEASURE_WEATHER_STATION_INT))
		{
			int wes_int = (int)json[RC_TB_KEY_MEASURE_WEATHER_STATION_INT];

			debug_print(F("Weather station read interval: "));
			debug_print(F("Current "));
			debug_print(DeviceConfig::get_wakeup_schedule_reason_int(SleepScheduler::WakeupReason::REASON_READ_WEATHER_STATION));
			debug_print(F(" - New "));
			debug_print(wes_int);
			debug_println(F(". "));
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

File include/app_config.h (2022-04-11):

#ifndef APP_CONFIG_H
#define APP_CONFIG_H
#include "struct.h"
#include "Arduino.h"
#include "sleep_scheduler.h"
#include "sdi12_sensor.h"

/** FW Version */
const int FW_VERSION = 165;

/******************************************************************************
 * Credentials
 * Should be defined in an app-specific /include/credentials.h file
 *****************************************************************************/

/** Thingsboard server URL */
extern const char TB_SERVER[];
/** Thingsboard server port */
extern const int TB_PORT;

/******************************************************************************
 * General
 *****************************************************************************/

/**
 * Enable redirecting all debug log messages to HTTP log service with Wifi.
 * Increases binary size significantly and slows down firmware execution. To be
 * used only for debugging. Wifi debug console uses the much larger ESP http
 * library because ArduinoHttpClient doesn't support SSL.
 */
#define WIFI_DEBUG_CONSOLE false

/**
 * Enable data submission through Wifi instead of GSM
 * For debugging purposes
 */
#define WIFI_DATA_SUBMISSION false

// Main switches

volatile const FLAGS_T FLAGS
{
    /** Debug mode enabled - set by build env*/
    #ifdef DEBUG
    DEBUG_MODE: true,
    #else
    DEBUG_MODE: false,
    #endif

    /* Enable logging of raw SDI12 communication. For debugging
    only, not memory efficient. */
    LOG_RAW_SDI12_COMMS: false,

    /** Enable redirecting all debug log messages to HTTP log service with Wifi */
    WIFI_DEBUG_CONSOLE_ENABLED: WIFI_DEBUG_CONSOLE,

    /** Submit data though WiFi instead of GSM */
    WIFI_DATA_SUBMISSION_ENABLED: WIFI_DATA_SUBMISSION,

    /** Enable Battery Gauge. */
    BATTERY_GAUGE_ENABLED: false,

    /** Enable solar panel current monitor */
    SOLAR_CURRENT_MONITOR_ENABLED: false,

    /** Enable NBIoT mode. If false GSM is used */
    NBIOT_MODE: false,
    
    /** When sleeping treat minutes as seconds. Used for debugging */
    SLEEP_MINS_AS_SECS: false,

    /** When true disables entering sleep charge and battery low modes when battery 
     * level under threshold */
    BATTERY_FORCE_NORMAL_MODE: false,

    /** Take measurements from water quality sensor */
    WATER_QUALITY_SENSOR_ENABLED: true,
    
    /** Take measurements from water level sensor */
    WATER_LEVEL_SENSOR_ENABLED: true,

    /** Take measurements from water presence sensor */
    WATER_PRESENCE_SENSOR_ENABLED: false,

    /** Take measurements from Atmos41 weather station */
    ATMOS41_ENABLED: false,

    /** Take measurements from soil moisture sensor */
    SOIL_MOISTURE_SENSOR_ENABLED: false,

    /** Return dummy values when measuring water quality */
    MEASURE_DUMMY_WATER_QUALITY: false,

    /** Return dummy values when measuring water level */
    MEASURE_DUMMY_WATER_LEVEL: false,

    /** Return dummy values when measuring weather data */
    MEASURE_DUMMY_WEATHER: false,

    LIGHTNING_SENSOR_ENABLED: false,

    /** Sync RTC automatically on preset intervals */
    RTC_AUTO_SYNC: false,

    /** Use external RTC when syncing time */
    EXTERNAL_RTC_ENABLED: true,

    /** Submit data to IPFS */
    IPFS: false
}; 

/** Print serial comms between the MCU and the GSM module (used by tinyGSM) */
#define PRINT_GSM_AT_COMMS false

/** Size of DataStore's buffer that holds uncommited data. Once this buffer
 is full, data is commited to flash */
const int DATA_STORE_BUFFER_ELEMENTS = 10;

/******************************************************************************
* RTC/Time
******************************************************************************/
/** NTP server used by GSM module for time sync */
const char NTP_SERVER[] PROGMEM = "pool.ntp.org";

/** Intervals on which RTC will be automatically synced when RTC auto sync is ON.
 * Interval is checked on call home so it is rounded to call home intervals */
const int RTC_AUTOSYNC_INTERVAL_MIN = 240;
/** 
 * Channel to use when capturing data from Water Level sensor 
*/
// const WaterLevelChannel WATER_LEVEL_INPUT_CHANNEL = WATER_LEVEL_CHANNEL_DFROBOT_ULTRASONIC_SERIAL;
const WaterLevelChannel WATER_LEVEL_INPUT_CHANNEL = WATER_LEVEL_CHANNEL_MAXBOTIX_PWM;
// const WaterLevelChannel WATER_LEVEL_INPUT_CHANNEL = WATER_LEVEL_CHANNEL_MAXBOTIX_SERIAL;

const AquatrollModel AQUATROLL_MODEL = AQUATROLL_MODEL_400;
// const AquatrollModel AQUATROLL_MODEL = AQUATROLL_MODEL_500;
// const AquatrollModel AQUATROLL_MODEL = AQUATROLL_MODEL_600;

/**
 * FineOffset weather station source: sniffer/uart
 */
const FineOffsetSource FO_SOURCE = FO_SOURCE_SNIFFER;
// const FineOffsetSource FO_SOURCE = FO_SOURCE_UART;

/**
 * Lightning sensor module to use
 */
#define LIGHTNING_SENSOR_MODULE LIGHTNING_SENSOR_DFROBOT

/** DFRobot */
#ifndef LIGHTNING_SENSOR_MODULE
#error "Lightning sensor module not set"
#endif

#if LIGHTNING_SENSOR_MODULE == LIGHTNING_SENSOR_DFROBOT
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

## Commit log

2020-04-24 Added pcb
    [carrier.PcbDoc, carrier.PrjPCB, carrier.SchDoc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]
2021-05-06 Added pcb 2.4.6
    [carrier.PcbDoc, carrier.PrjPCB, carrier.SchDoc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]
2022-04-11 Latest updates
    [carrier_tsim.GBL, carrier_tsim.GBO, carrier_tsim.GBS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]
